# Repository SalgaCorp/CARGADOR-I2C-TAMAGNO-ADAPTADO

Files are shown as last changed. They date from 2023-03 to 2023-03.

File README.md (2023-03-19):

# CARGADOR-TAMAÑO-ADAPTADO

**Objetivos**:

1.- Open Source.

2.- Que el tamaño sea similar al cargador TP4056 para usar en proyectos ya existentes.

3.- Que tenga monitoreo de variables de batería: voltaje, %carga, etc.

# **Contenido del repositorio**:

PCB
Datasheet
Fotos

# *Documentation*:

Usa los siguientes componentes importantes:

Datasheet (BQ24075 Charger)

[bq24075.pdf](https://github.com/SalgaCorp/CARGADOR-TAMAGNO-ADAPTADO/files/10971589/bq24075.pdf)

Datasheet (BQ27441-G1 Fuel Gauge)

[bq27441-g1.pdf](https://github.com/SalgaCorp/CARGADOR-TAMAGNO-ADAPTADO/files/10971591/bq27441-g1.pdf)

Para monitoreo de variables de batería usar la siguiente libreria y ejemplos de cortesia de SpurkFun:  

https://github.com/sparkfun/SparkFun_BQ27441_Arduino_Library

Comparacion de PCB con tamaño del cargador TP4056

PCB vs Tamaño PCB alternativa

PCB coincide

# Product Versions: DEMO

Luego subiré la pcb armada completamente.

# License Information
This product is open source!

# Contact Us
Call or WhatsApp 
https://api.whatsapp.com/send?phone=56966814899

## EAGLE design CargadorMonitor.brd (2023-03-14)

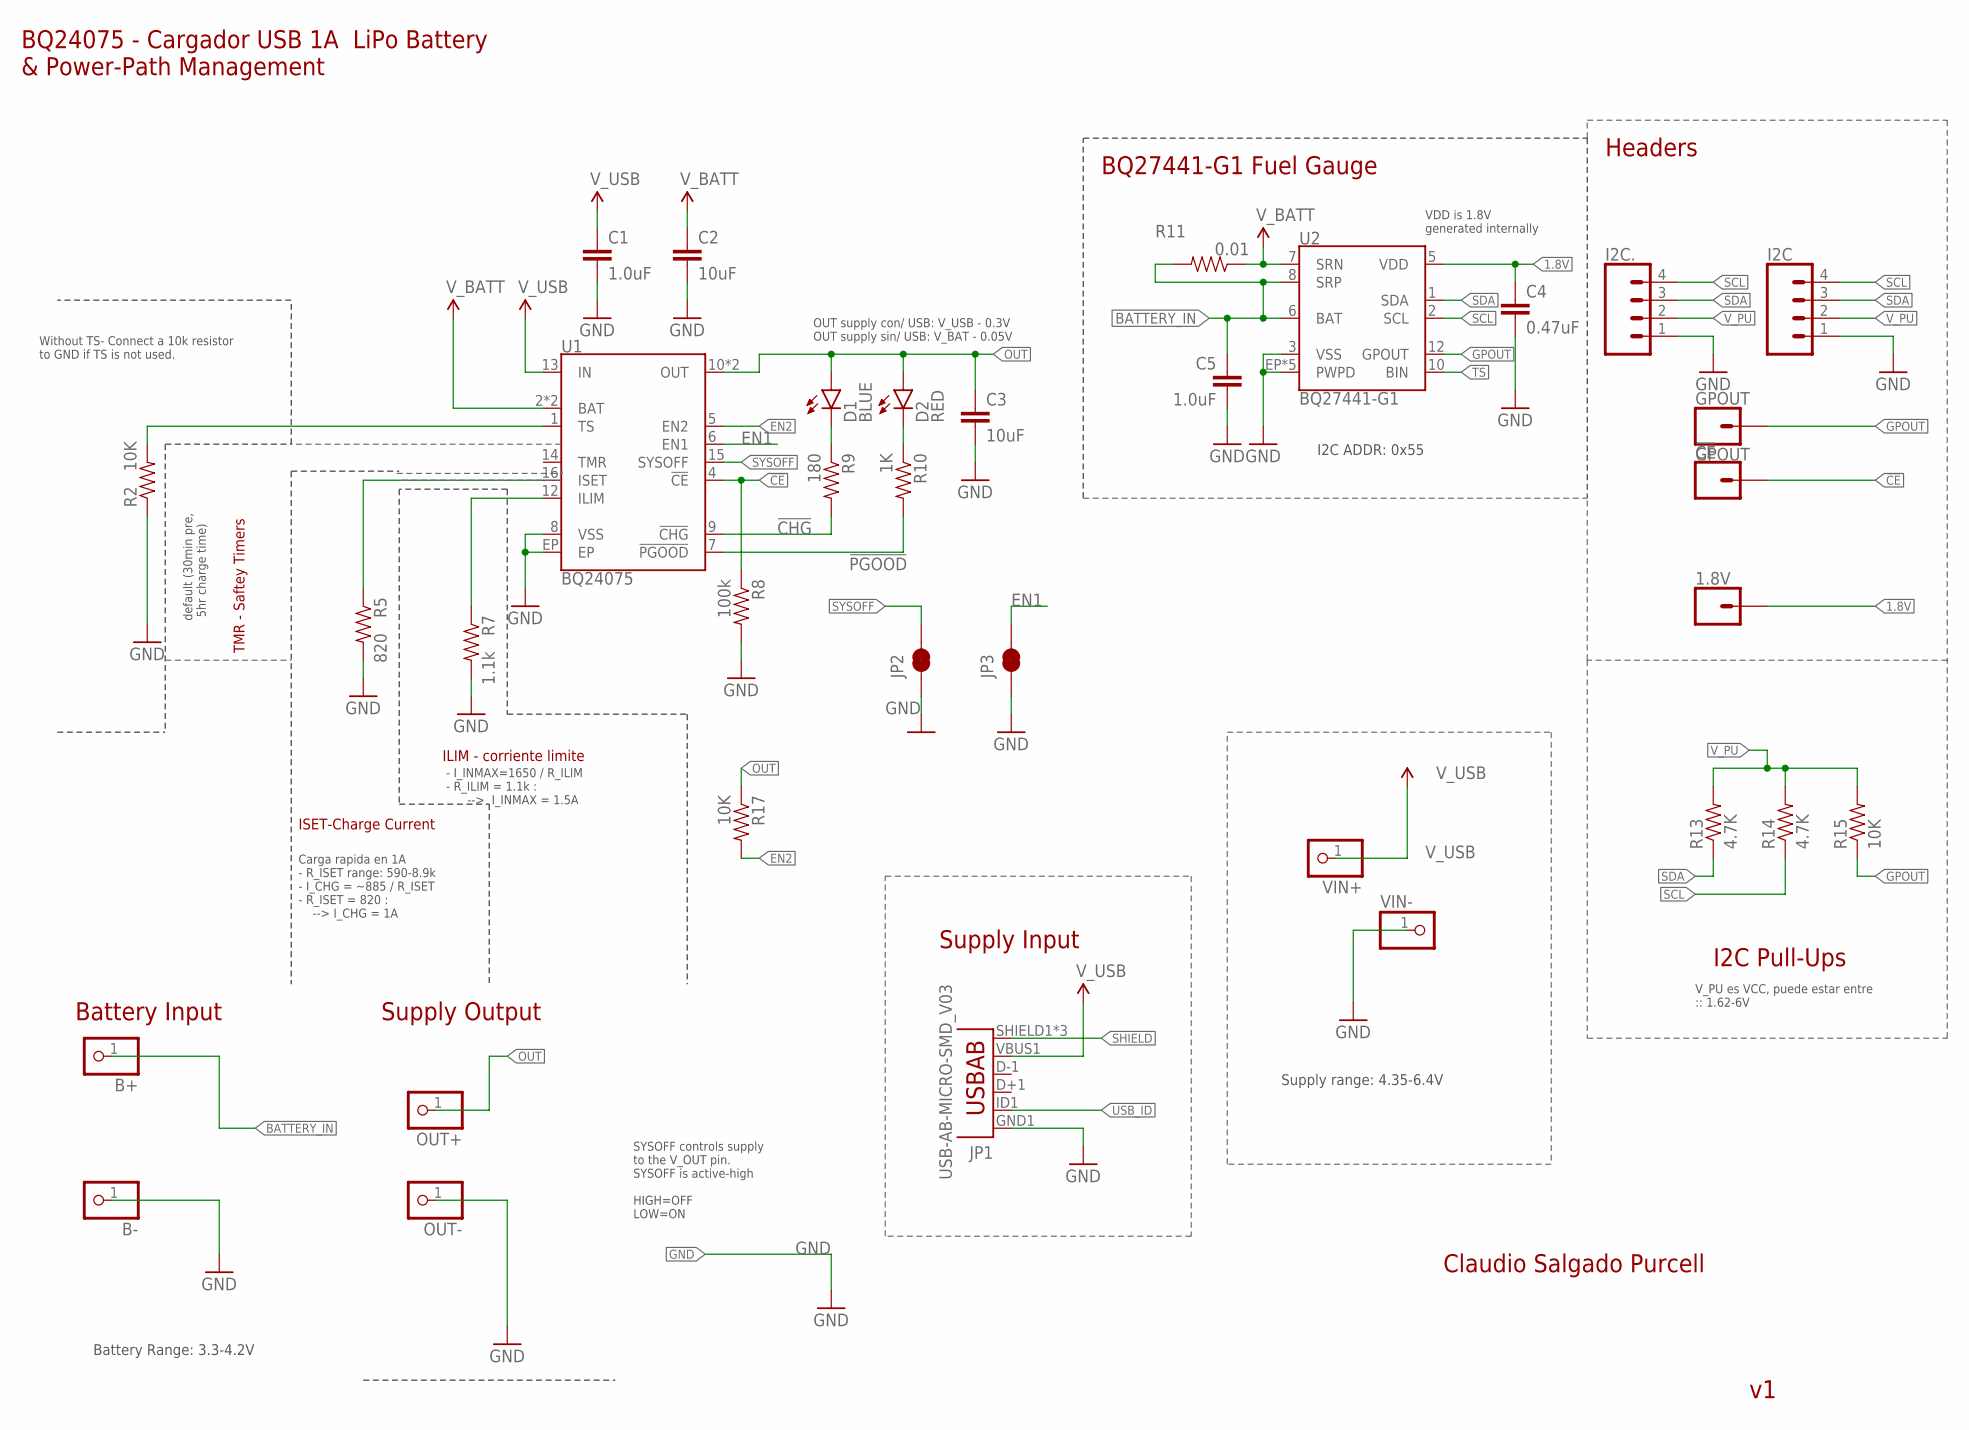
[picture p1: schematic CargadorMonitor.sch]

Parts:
1.8V: CONN_01PTH_NO_SILK_SMALL; 1X01_SMALL
!CE!: CONN_01PTH_NO_SILK_SMALL; 1X01_SMALL
B+: PINHD-1X1; 1X01
B-: PINHD-1X1; 1X01
C1: 1.0uF; 1206-CAP
C2, C3: 10uF; 0805-CAP
C4: 0.47uF; 0603-CAP
C5: 1.0uF; 0603-CAP
D1: BLUE; LED-0603
D2: RED; LED-0603
GPOUT: GPOUT; 1X01_SMALL
I2C: CONN_04SMD2; JST04_1MM_RA
I2C.: CONN_041.27MM; 1X04_1.27MM
JP1: USB-AB-MICRO-SMD_V03
JP2, JP3: JUMPER-SMT_2_NC_TRACE_SILK; SMT-JUMPER_2_NC_TRACE_SILK
OUT+: PINHD-1X1; 1X01
OUT-: PINHD-1X1; 1X01
R2, R15, R17: 10K; 0603-RES
R5: 820; 0603-RES
R7: 1.1k; 0603-RES
R8: 100k; 0603-RES
R9: 180; 0603-RES
R10: 1K; 0603-RES
R11: 0.01; 1206
R13, R14: 4.7K; 0603-RES
U1: BQ24075; PVQFN-N16
U2: BQ27441-G1; PDSO-N12
VIN+: PINHD-1X1; 1X01
VIN-: PINHD-1X1; 1X01

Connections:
1.8V: 1.8V.P$1, C4.1, U2.5 (VDD)
!CE!: !CE!.P$1, R8.1, U1.4 (!CE!)
!CHG!: R9.2, U1.9 (!CHG!)
!PGOOD!: R10.2, U1.7 (!PGOOD!)
BATTERY_IN: B+.1, C5.1, R11.2, U2.6 (BAT), U2.8 (SRP)
EN1: JP3.2, U1.6 (EN1)
EN2: R17.2, U1.5 (EN2)
GND: B-.1, C1.2, C2.2, C3.2, C4.2, C5.2, I2C.1, I2C..1, JP1.GND1 (GND), JP2.1, JP3.1, OUT-.1, R2.1, R5.2, R7.2, R8.2, U1.8 (VSS), U1.EP, U2.3 (VSS), U2.EP (PWPD), U2.EP1 (PWPD), U2.EP2 (PWPD), U2.EP3 (PWPD), U2.EP4 (PWPD), VIN-.1
GPOUT: GPOUT.P$1, R15.1, U2.12 (GPOUT)
ILIM: R7.1, U1.12 (ILIM)
ISET: R5.1, U1.16 (ISET)
unnamed: D1.C, R9.1
unnamed: D2.C, R10.1
OUT: C3.1, D1.A, D2.A, OUT+.1, R17.1, U1.10 (OUT), U1.11 (OUT)
SCL: I2C.4, I2C..4, R14.1, U2.2 (SCL)
SDA: I2C.3, I2C..3, R13.1, U2.1 (SDA)
SHIELD: JP1.SHIELD1 (SHIELD), JP1.SHIELD2 (SHIELD), JP1.SHIELD3 (SHIELD)
SYSOFF: JP2.2, U1.15 (SYSOFF)
TS: R2.2, U1.1 (TS), U2.10 (BIN)
USB_ID: JP1.ID1 (USBID)
V_BATT: C2.1, R11.1, U1.2 (BAT), U1.3 (BAT), U2.7 (SRN)
V_PU: I2C.2, I2C..2, R13.2, R14.2, R15.2
V_USB: C1.1, JP1.VBUS1 (VBUS), U1.13 (IN), VIN+.1

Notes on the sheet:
Carga rapida en 1A - R_ISET range: 590-8.9k - I_CHG = ~885 / R_ISET - R_ISET = 820 : --> I_CHG = 1A
- I_INMAX=1650 / R_ILIM - R_ILIM = 1.1k : --> I_INMAX = 1.5A
Supply Input
Battery Input
Supply Output
BQ24075 - Cargador USB 1A LiPo Battery & Power-Path Management
I2C Pull-Ups
BQ27441-G1 Fuel Gauge
Headers
Claudio Salgado Purcell
SYSOFF controls supply to the V_OUT pin. SYSOFF is active-high HIGH=OFF LOW=ON
ILIM - corriente limite
ISET-Charge Current
TMR - Saftey Timers
default (30min pre, 5hr charge time)
Without TS- Connect a 10k resistor to GND if TS is not used.
V_PU es VCC, puede estar entre :: 1.62-6V
Supply range: 4.35-6.4V
VDD is 1.8V generated internally
OUT supply con/ USB: V_USB - 0.3V OUT supply sin/ USB: V_BAT - 0.05V
I2C ADDR: 0x55
Battery Range: 3.3-4.2V

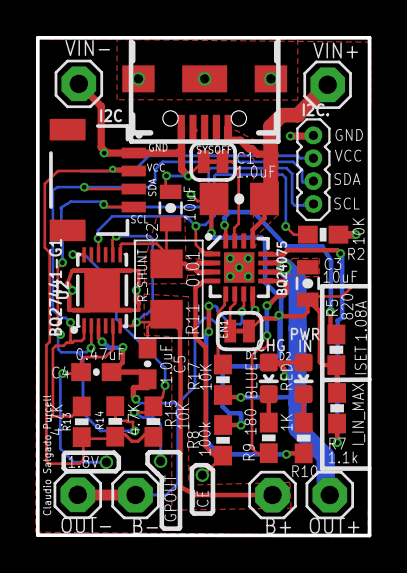
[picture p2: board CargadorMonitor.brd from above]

Board: 2 copper layers, 18.4 x 27.6 mm, 34 parts (0 on the bottom side), 22 nets.

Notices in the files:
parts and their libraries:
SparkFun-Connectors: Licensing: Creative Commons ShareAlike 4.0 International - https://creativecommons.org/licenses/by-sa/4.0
